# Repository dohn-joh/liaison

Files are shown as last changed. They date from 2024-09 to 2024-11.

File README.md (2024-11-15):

cover_photo

# Liaison
`Liaison` is a wireless 36-key split keyboard that leverages custom keycaps, splay, and tenting for ergonomics.

**Video showcase**:  
[Fit and layout](https://vimeo.com/1022366207)  
[Typing test](https://vimeo.com/1022366241)

***

# Components

## Case and Tenting Legs
[Here](case) you can find models for the case and magsafe tenting legs.  
Print 1 of each of the following:
* [top left](case/case_top_left.step)
* [top right](case/case_top_right.step)
* [bottom left](case/case_bottom_left.step)
* [bottom right](case/case_bottom_right.step)

[Tenting legs](case/magsafe_tenting_leg) (optional)  
[Dongle case](https://github.com/dohn-joh/dongle-zmk) (optional)

## Required Parts
|Part|Quantity|Link|
|-|:-:|-|
|Microcontroller: Xiao nRF52840|1|https://www.seeedstudio.com/Seeed-XIAO-BLE-nRF52840-p-5201.html|
|Battery: 301230 with molex pico ezmate connector|1|Select L0040. https://www.aliexpress.us/item/3256802674181210.html|
|Battery connector: molex pico ezmate 1x02|1|Select 2P. https://www.aliexpress.us/item/3256805726980487.html|
|Power button: 1208YD|1|https://www.aliexpress.us/item/3256801267126259.html|
|Reset button: SKHLLCA010|1|https://www.aliexpress.us/item/3256805176534062.html|
|M2 heatset inserts (OD:3.2, Height: 2-3mm)|8|https://www.aliexpress.us/item/3256804856964661.html|
|Switches|36|Your choice of choc v1 or v2. Recommended: Lofree ghost, swap springs|
|Kailh Choc PG1350 Hot Swap Sockets|36|https://www.aliexpress.us/item/3256803687338432.html|
|Silicone sheet for feet|1|https://www.amazon.com/dp/B09NW63JLC|
|Keycaps|36|Your choice. Recommended: [low profile DES](https://github.com/dohn-joh/PseudoMakeMeKeyCapProfiles) + [lever keycaps](https://github.com/dohn-joh/keycaps)|

> [!NOTE]
> Keycap dimensions must be ≤17.85mm wide and ≤18mm deep. All standard choc keycaps will fit.

## Optional Parts for Tenting Legs and Magnetic USB
|Part|Quantity|Link|
|-|:-:|-|
|Magsafe puck: Vrig MG-01|2|https://www.aliexpress.us/item/3256804940825578.html|
|Magsafe plate|2|https://www.amazon.com/dp/B09B6XGTWL|
|1/4" thread screw ~9mm|2|There are cheaper sources out there, but here is a link: https://www.amazon.com/dp/B01MS60KSY|
|Magnetic USB connector/cable: Netdot Gen10|2|https://www.amazon.com/dp/B07MBD3FZD|

## Firmware
[Here](https://github.com/dohn-joh/liaison-zmk-module) you can find the liaison's ZMK module. The firmware is configured for dongle usage, however you may fork the repo if you prefer to not use a dongle.

# Build Guide

**1. Order the pcb and acquire the case**
* Download the [left](ergogen/output/pcbs/production/Left_v1.0.0.zip) and [right](ergogen/output/pcbs/production/Right_v1.0.0.zip) pcb zip files.
* Upload the zip files to your pcb manufacturer of choice, then place an order. I used jlcpcb.
* Acquire the case:
    * If you own a 3d printer: print the [case](README.md#case-and-tenting).
    * If you don't own a 3d printer: order the case prints using [these files](README.md#case-and-tenting).

**2. Order [parts](README.md#required-parts)**

**3. Flash and test the microcontrollers**
> [!IMPORTANT]
> **Flash your microcontrollers with firmware and test them before doing any soldering.** Once the microcontrollers are soldered, they will be nearly impossible to remove without the right tools.
* Flash the [firmware](https://github.com/dohn-joh/liaison-zmk-module).
* Test to make sure that the microcontrollers are working and not defective (defective units are rare, but it happens).

**4. Solder components to top face of pcb**
* Set your soldering iron to 350C.
* Solder the microcontrollers, diodes, [reset switch](https://github.com/GEIGEIGEIST/TOTEM/blob/main/docs/buildguide.md#reset-switches), power switch, and battery connector to the top face of the pcb.
* The battery connector can be tricky to solder. But once you get the hang of it, it's pretty easy. Here are some tips from Kim:
    > Apply flux on both the pcb pads and battery connector pins  
    Tin both corner pads with solder  
    Solder connector to the first corner by applying heat to the corner metal pin from above  
    Then do the same for the second corner  
    Apply more flux to connector pins and PCB pads  
    Apply solder to underside of soldering tip  
    Drag iron from side to side over the contacts until they are soldered. The solder will just jump to where it needs to go  
    Make sure to clean the flux thoroughly
* The power button needs to face downward. Trim the power switch legs to size before installing. Secure the power switch in place with kapton tape after soldering.

**5. Check your work**
* This step is optional, but I like to check my work before moving on to soldering the other side of the pcb.
* Make sure all diodes are oriented correctly. All lines or arrows should be pointing left.
* Set your multimeter to continuity mode.
* Check connections and look for bridging.
* Fix any solder joints as needed.

**6. Solder components to bottom face of pcb**
> [!IMPORTANT]
> Hotswap socket orientation matters. The sockets must align with the silkscreen or the bottom case will not fit.
* Solder the hotswap sockets to the bottom face of the pcb.
* Optional: check your work with a multimeter.

**7. Battery installation**
* Plug the battery into the connector.
* Use kapton tape to secure the battery within the silkscreen outline.

**8. Case assembly**
* With your soldering iron set to 300C, push heatset inserts into the 4 holes on the top case.
* Insert the pcb.
* Attach the bottom case and secure it in place with the M2 screws.
    * If the bottom case doesn't sit flush in the area around the reset switch, then you may need to trim the reset switch legs.
* Cut silicone sheet to size and adhere to the corners of the bottom case.
* Insert the switches and keycaps.

**9. (Optional) Tenting assembly**
* Screw the magsafe pucks onto the tenting legs.
* Adhere magsafe plate to bottom case.
* Cut silicone sheet to size and adhere to bottom of tenting legs.

***

# Photos





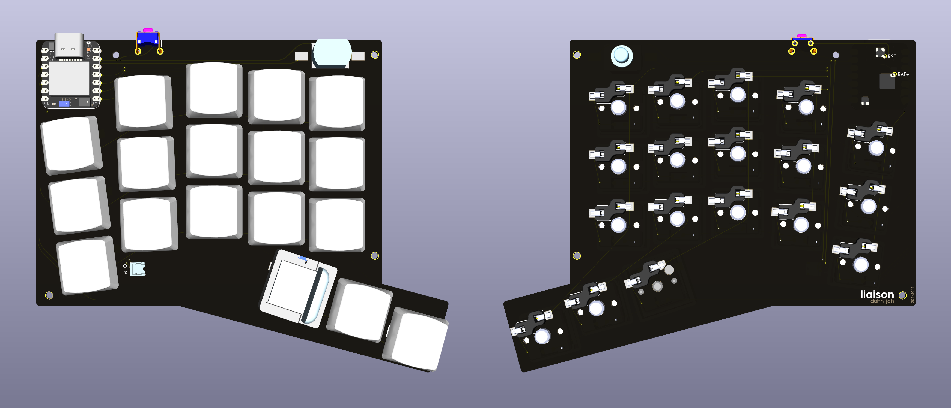
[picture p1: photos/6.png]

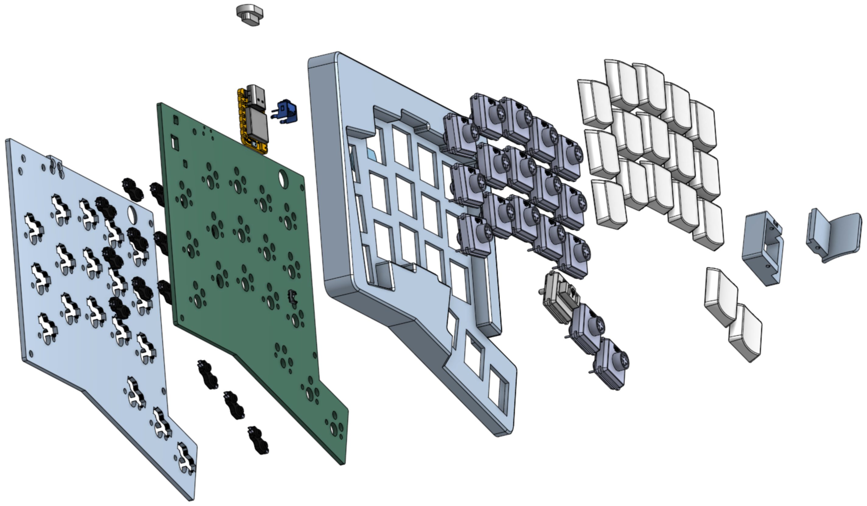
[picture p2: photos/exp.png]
exp


***

## Thanks
These people and many more helped make this keyboard possible. Yall are legends.
```
MrZealot
Pseudoku
petejohanson
caksoylar(bravekarma)
jcmkk3
ceoloide
infused-kim
Flatfootfox
sadekbaroudi
zzeneg
joelspadin
wolfwood
claussen
Geist
rmwphd(atinyzubat)
fish
Araxia
honorless
elkepenin
reeves
```

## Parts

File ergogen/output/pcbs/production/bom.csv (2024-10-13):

Designator | Footprint | Quantity | Value | LCSC Part #
CONN1 | conn_molex_pico_ezmate_1x02 | 1
D1, D10, D11, D12, D13, D14, D15, D16, D17, D18, D2, D3, D4, D5, D6, D7, D8, D9 | ComboDiode | 18
H1, H2, H3 | mounting_hole | 3
MCU1 | xiao_smd_xl_cutout_minimal | 1
S19 | SKHLLCA010 | 1 | SKHLLCA010
SW1 | 1208YD | 1

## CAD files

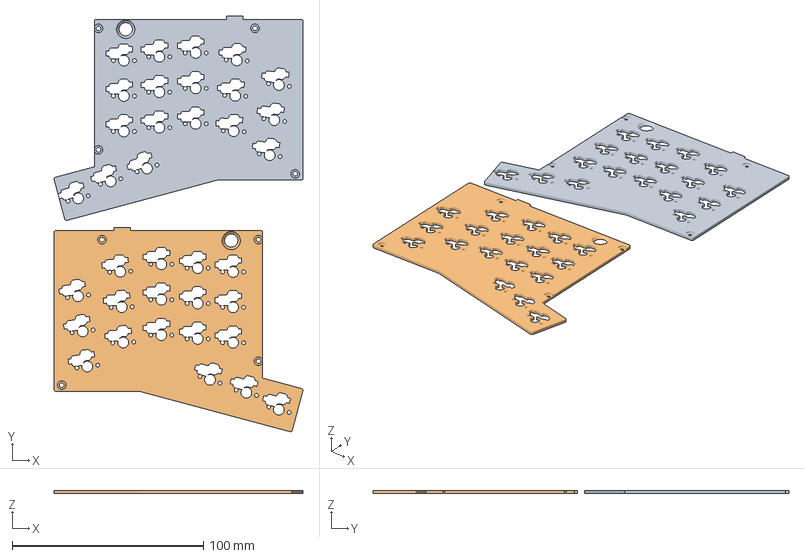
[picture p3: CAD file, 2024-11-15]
case/case_bottom_orcaslicer_settings.3mf
130.1 x 217.1 x 1.70 mm
test.step
test2.step

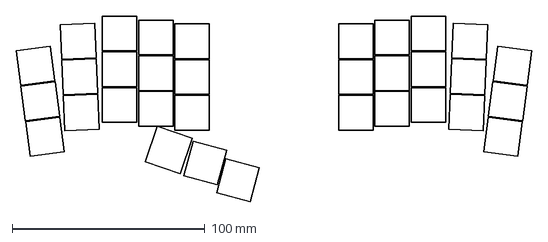
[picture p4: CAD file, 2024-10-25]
ergogen/output/outlines/keycaps.dxf
267.0 x 96.2 mm

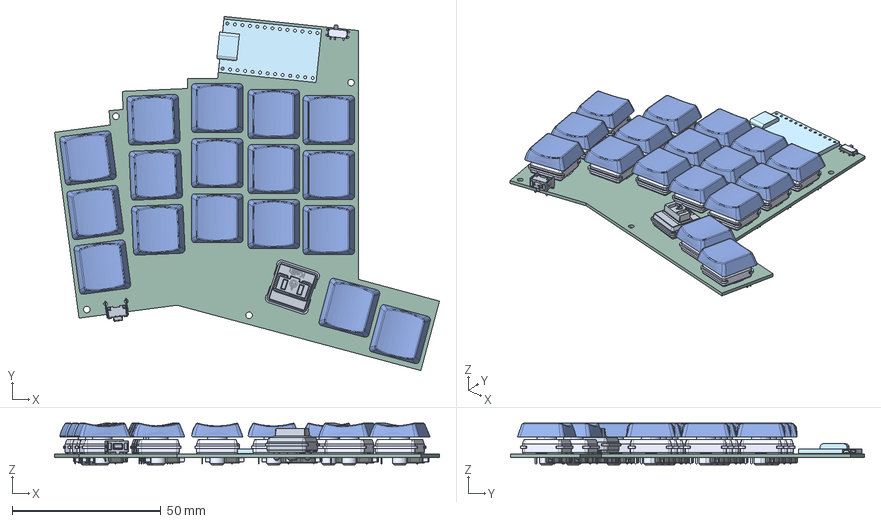
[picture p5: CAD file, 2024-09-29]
ergogen/output/pcbs/l.step
129.4 x 119.0 x 14.0 mm
SKHLLC
supermini-nrf52840
PCM12SMTR
Kailh_PG1352 x 17
PG1350 x 18
cap x 17
Kailh LP Choc Burnt Orange
Sybil_PCB

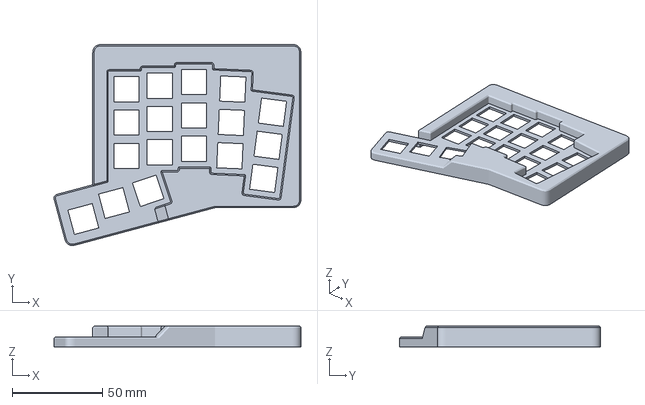
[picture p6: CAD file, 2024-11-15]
case/case_top_orcaslicer_settings.3mf
137.0 x 111.5 x 11.5 mm

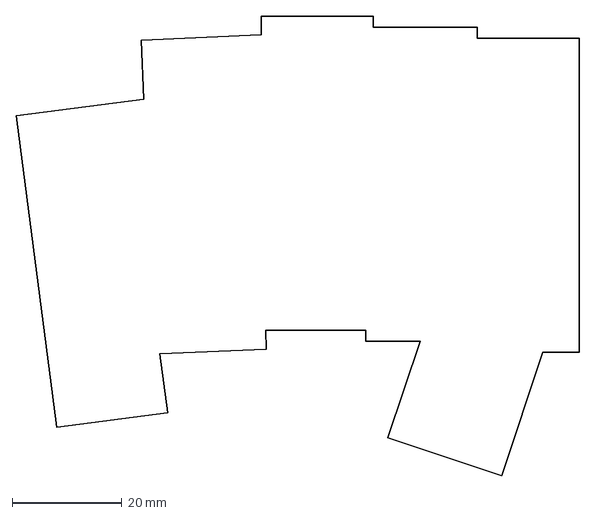
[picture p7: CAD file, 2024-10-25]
ergogen/output/outlines/key_walls.dxf
102.5 x 83.7 mm

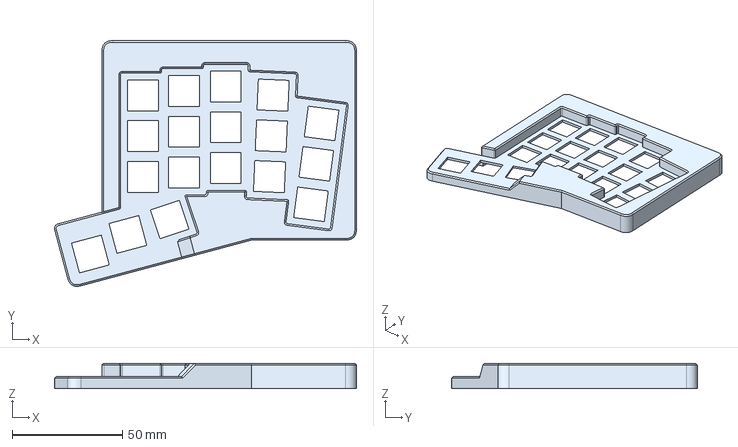
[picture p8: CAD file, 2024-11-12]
case/case_top_right.step
137.0 x 111.5 x 11.5 mm

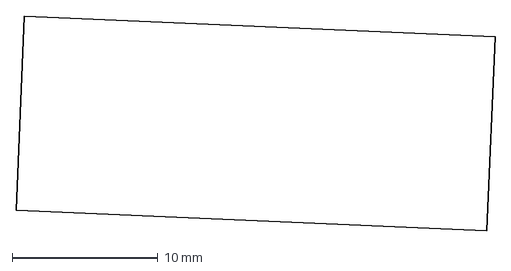
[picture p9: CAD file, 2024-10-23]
ergogen/output/outlines/battery_cutout_right.dxf
32.8 x 14.7 mm

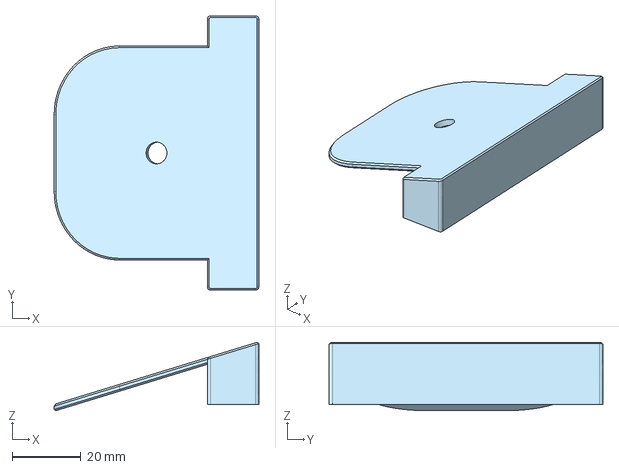
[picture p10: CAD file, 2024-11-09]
case/magsafe_tenting_leg.step
59.8 x 80.0 x 20.0 mm

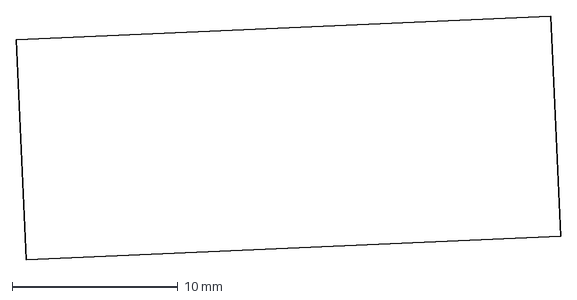
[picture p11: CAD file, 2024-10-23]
ergogen/output/outlines/battery_cutout_left.dxf
32.8 x 14.7 mm

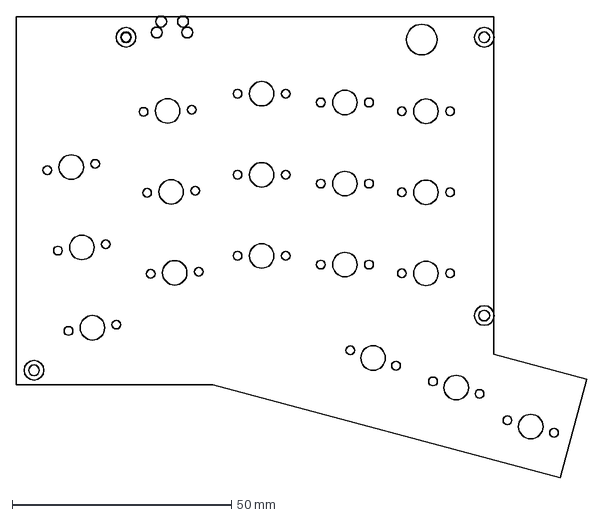
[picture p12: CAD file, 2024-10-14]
ergogen/output/outlines/case_bottom_left.dxf
130.3 x 105.4 mm

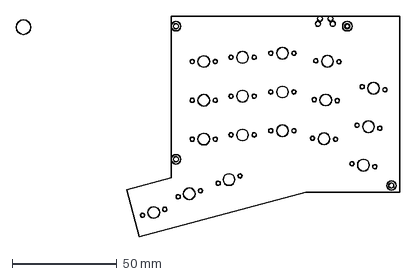
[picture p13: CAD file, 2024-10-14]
ergogen/output/outlines/case_bottom_right.dxf
183.1 x 105.4 mm

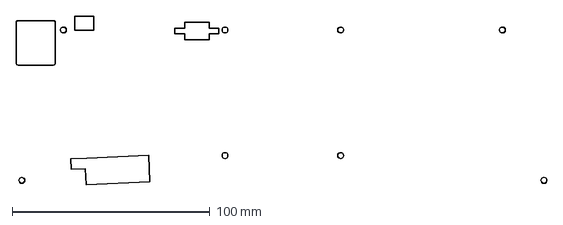
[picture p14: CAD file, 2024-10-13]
ergogen/output/outlines/case_top_cutouts.dxf
268.4 x 85.0 mm

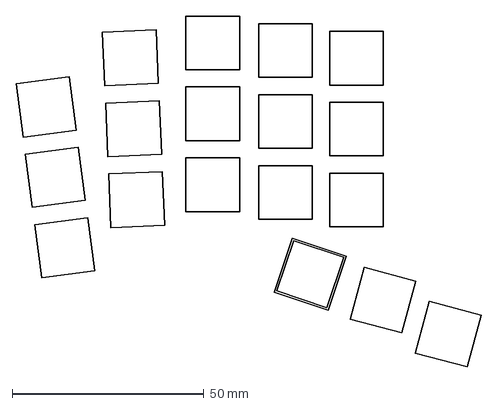
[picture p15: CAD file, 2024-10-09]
ergogen/output/outlines/switch_cutouts.dxf
121.3 x 91.5 mm

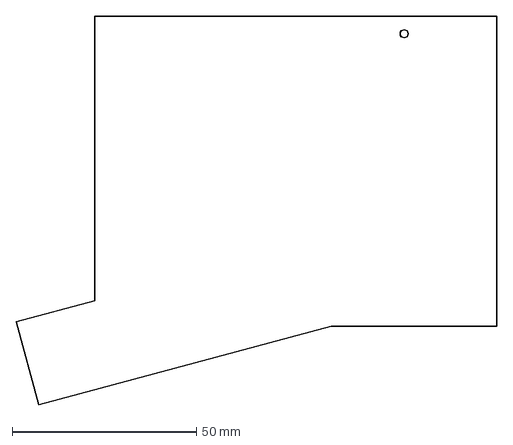
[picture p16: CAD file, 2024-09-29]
ergogen/output/outlines/pcb_right.dxf
130.3 x 105.3 mm

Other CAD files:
case/case_top_left.step
ergogen/output/outlines/pcb_left.dxf
ergogen/output/outlines/screws.dxf

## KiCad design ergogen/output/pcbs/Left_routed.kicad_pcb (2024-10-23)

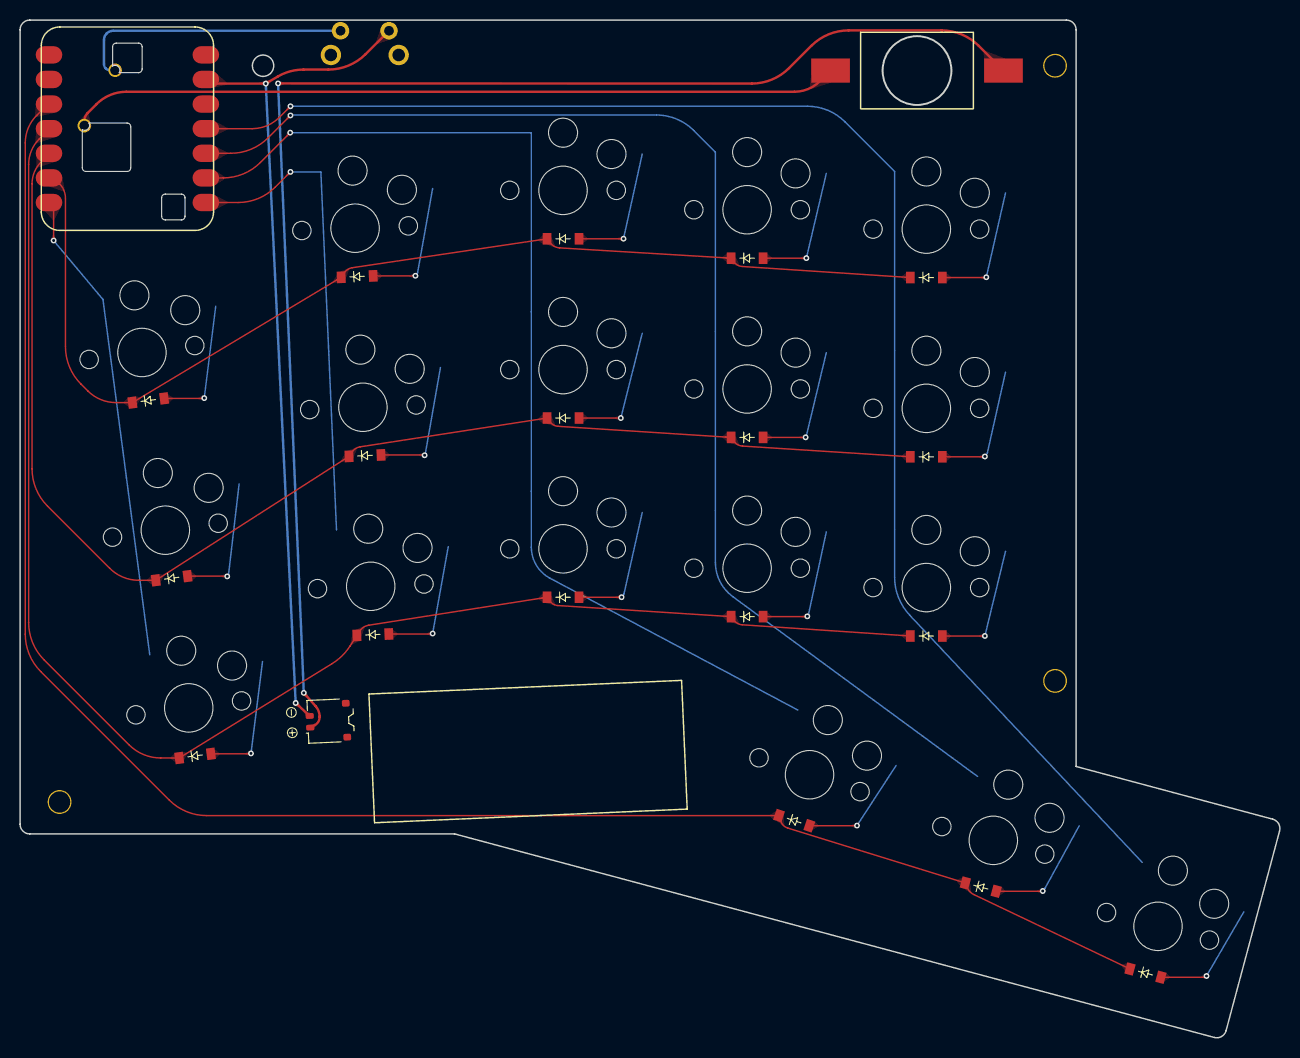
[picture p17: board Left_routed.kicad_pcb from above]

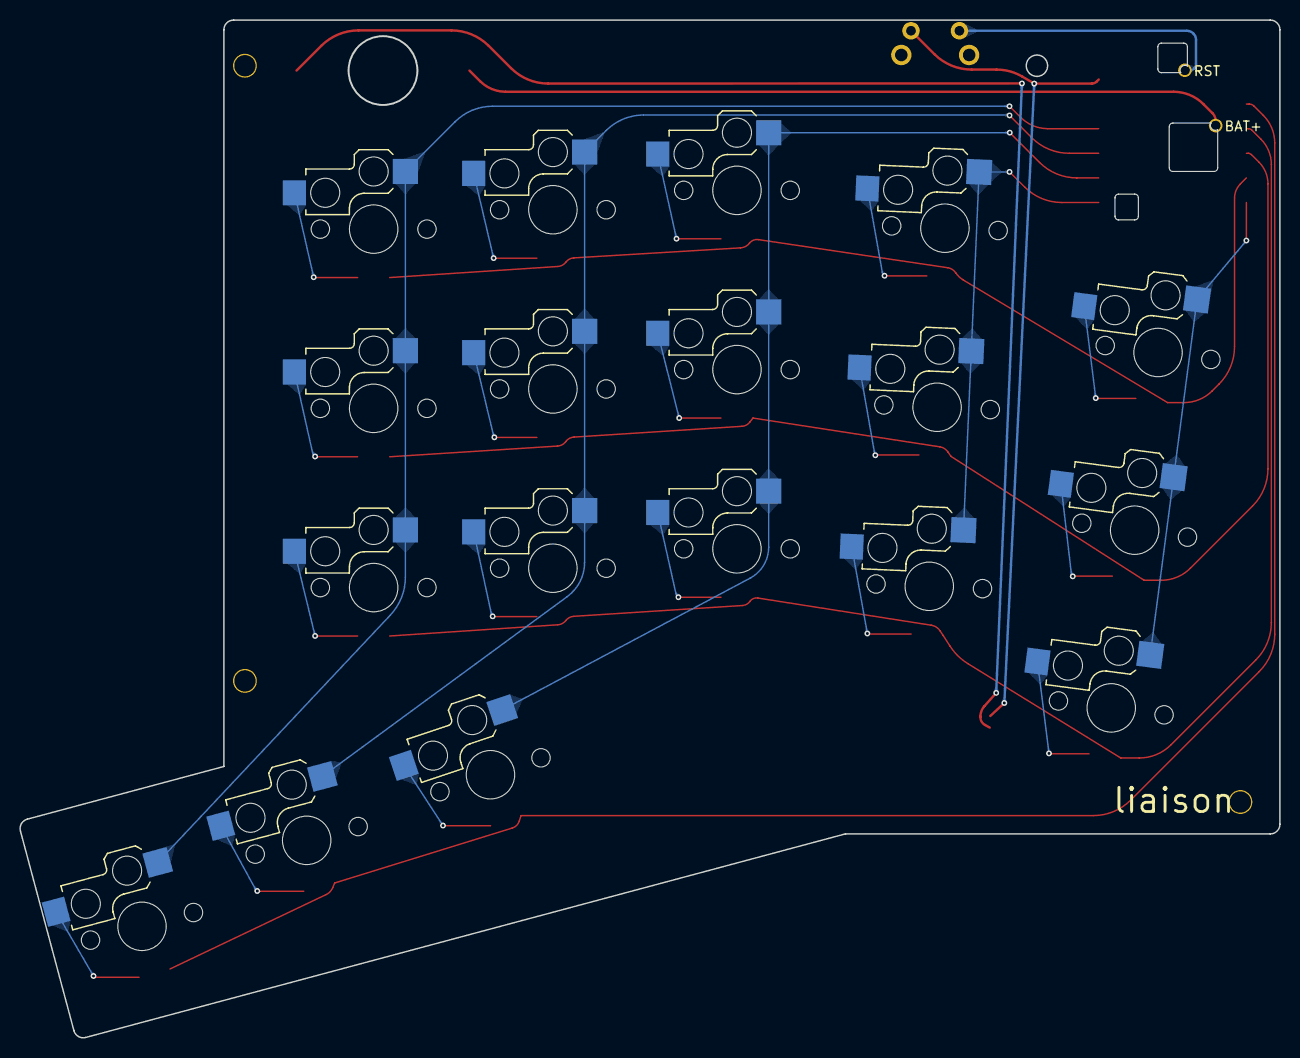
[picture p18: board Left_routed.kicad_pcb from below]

Board: 2 copper layers, 130.0 x 105.0 mm, 44 parts (18 on the bottom side), 31 nets.

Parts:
CONN1: conn_molex_pico_ezmate_1x02
D1, D2, D3, D4, D5, D6, D7, D8, D9, D10, D11, D12, D13, D14, D15, D16, D17, D18: ComboDiode
H1, H2, H3: mounting_hole
ICON1: icon_bat
MCU1: xiao_smd_xl_cutout_minimal
S1, S2, S3, S4, S5, S6, S7, S8, S9, S10, S11, S12, S13, S14, S15, S16, S17, S18: switch_choc_v1_v2
S19: SKHLLCA010
SW1: 1208YD

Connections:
BAT: MCU1.19, SW1.1
BAT_CONN: CONN1.1, SW1.2
C0: MCU1.7, S1.1, S2.1, S3.1
C1: MCU1.8, S4.1, S5.1, S6.1
C2: MCU1.9, S7.1, S8.1, S9.1, S16.1
C3: MCU1.10, S10.1, S11.1, S12.1, S17.1
C4: MCU1.11, S13.1, S14.1, S15.1, S18.1
GND: CONN1.2, MCU1.13, S19.2
R0: D3.1, D6.1, D9.1, D12.1, D15.1, MCU1.6
R1: D2.1, D5.1, D8.1, D11.1, D14.1, MCU1.5
R2: D1.1, D4.1, D7.1, D10.1, D13.1, MCU1.4
R3: D16.1, D17.1, D18.1, MCU1.3
RST: MCU1.17, S19.1
base_cluster: D17.2, S17.2
extension_cluster: D18.2, S18.2
flexion_cluster: D16.2, S16.2
index_bottom: D10.2, S10.2
index_home: D11.2, S11.2
index_top: D12.2, S12.2
inner_bottom: D13.2, S13.2
inner_home: D14.2, S14.2
inner_top: D15.2, S15.2
middle_bottom: D7.2, S7.2
middle_home: D8.2, S8.2
middle_top: D9.2, S9.2
pinky_bottom: D1.2, S1.2
pinky_home: D2.2, S2.2
pinky_top: D3.2, S3.2
ring_bottom: D4.2, S4.2
ring_home: D5.2, S5.2
ring_top: D6.2, S6.2

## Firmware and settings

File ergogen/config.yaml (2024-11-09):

units:
  capx: 17.85
  capy: 18
  capthumbx: 17.95
  capthumby: 18.35
  capleverx: 19.12
  caplevery: 19.32
  kx: 19
  ky: 18.5
  inner_spread: kx-0.5
  pinky_splay: 5
  ring_splay: 2.5
  thumb_offsetx: 0.25kx
  switch_xy_mx: 14 # switch hole
  switch_xy_choc: 13.8
  angle: 22 # was 27.5
  # sf: 19.151 # may want to change this for fab
  sf: 19.151
  
  # pcb rectangle dimensions
  pcbx: 109
  pcby: 84

  # mirror distance
  md: 250

  ## nice!nano dimensions (from Nicell himself)
  # mcux: 18
  # mcuy: 33.4
  ## supermini dimensions
  # mcux: 18.1 # with 0.1mm tolerance for fr4 variance
  # mcuy: 33.85 # length from usb to end of pcb
  ## promicro footprint dimensions
  # mcux: 17.78
  # mcuy: 33.02 # board only, no usb
  # xiao nrf52840 dimensions
  mcux: 17.78
  mcuy: 21
  # netdot usb adapter dimensions
  ndx: 12 # actual is ~10.82 at widest section
  ndy: 6 # actual is 5.4 while plugged in
  # space between keycap and case wall
  wallx: 1.25
  wally: 1.1

  # joycon battery dimensions plus tolerance
  # bcx: 24.5+0.7
  # bcy: 52+0.7

  # 301230 battery dimensions
  bcx: 31.5+0.8
  bcy: 12.5+0.8

  # screw hole diameter (M2)
  scd: 2.2
  # screw head diameter ~3.3
  # heatset hole diameter for 3.2 OD inserts
  heatset: 3
  # screw hole diameter for case bottom
  scb: 2.45
  # screwhead diameter
  sch: 4.5

points:
  zones:
    matrix:
      anchor:
        # Fix placement on KiCAD sheet.
        shift: [100, -100]
        rotate: pinky_splay + ring_splay
      key:
        width: capx
        height: capy
        padding: ky
        spread: kx
        autobind: 0
      columns:
        pinky:
          rows:
            top:
              bind: [0, 0.5kx, 0.5ky, 0]
            home:
              bind: [0, 0.5kx, 0, 0]
            bottom:
              bind: [0, 0, 0, 0]
          key:
            column_net: C0
            tags: hotswap
        ring:
          rows:
            top:
              bind: [0, 0.5kx, 0.5ky, 0]
            home:
              bind: [0.5ky, 0.5kx, 0, 0]
            bottom:
              bind: [0.5ky, 0, 0, 0.5kx]
          key:
            column_net: C1
            stagger: 10 # was 10
            spread: kx+1
            splay: -pinky_splay
            origin: [0, -3]
            tags: hotswap
        middle:
          rows:
            home:
              bind: [0.5ky, 0.5kx, 0, 0]
            bottom:
              bind: [0.5ky, 0.5kx, 0.5ky, 0.5kx]
          key:
            column_net: C2
            stagger: 3 # was 2
            spread: kx+1
            splay: -ring_splay
            tags: hotswap
        index:
          rows:
            top:
              bind: [0, 0, 0, 0]
            home:
              bind: [0.5ky, 0.5kx, 0, 0]
            bottom:
              bind: [0.5ky, 0.5kx, 0, 0]
          key:
            column_net: C3
            stagger: -2
            tags: hotswap
        inner:
          rows:
            top:
              bind: [0, 0, 0, 0.5kx]
            home:
              bind: [0.5ky, 0, 0, 0]
            bottom:
              bind: [0.5ky, 0, 0.5ky, 0]
              tags: hotswap
          key:
            column_net: C4
            spread: inner_spread
            stagger: -2
      rows:
        bottom:
          row_net: R2
        home:
          row_net: R1
        top:
          row_net: R0
    thumb:
      anchor:
        ref: matrix_index_bottom
        shift: [thumb_offsetx-4.82+3, -30.1+3]
      key:
        width: capx
        height: capy
        padding: ky
        spread: kx+0.7
        autobind: 0
      columns:
        flexion:
          rows:
            cluster:
              bind: [0.5ky, 0, 0, 0]
          key:
            splay: -20
            orient: 47.5
            shift: [152.1536-148.8676+2.5, -(139.4486-142.9557)] # x was +1.6
            rotate: -46
            column_net: C2
        base:
          rows:
            cluster:
              bind: [0, 18.715231, 0, 0]
          key:
            splay: 5
            stagger: 2.5+4
            spread: cx+2.5
            column_net: C3
            adjust:
              orient: angle - pinky_splay - ring_splay + 20 + 3
              shift: [0.887, -0.4617]
              rotate: -angle + pinky_splay + ring_splay - 20 - 3
        extension:
          rows:
            cluster:
              bind: [0, 0, 0, 90]
          key:
            column_net: C4
            stagger: -4
      rows:
        cluster:
          row_net: R3
    ref_polygon:
      anchor:
    ref_mcu:
      anchor:
        ref: matrix_pinky_top
        shift: [-1.5, 23.1]
        orient: -7.5
    ref_reset:
      anchor:
        ref: ref_mcu
        shift: [24.5, 8.858]
    ref_power:
      anchor:
        ref: ref_mcu
        shift: [81.5, 6.]
    ref_battery_connector:
      anchor:
        ref: matrix_ring_bottom
        shift: [-5, -14+0.303]
        rotate: 90
    ref_battery_icon:
      anchor:
        ref: ref_battery_connector
        shift: [0, 3.75]
    ref_jlc_text:
      anchor:
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

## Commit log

2024-09-30 update sw cut
    [switch_cutouts.dxf]
2024-10-09 fix xiao footprint
    [Left.kicad_pcb, Right.kicad_pcb, switch_cutouts.dxf]
2024-10-13 update config
    [Left.kicad_pcb, Left_render.kicad_pcb, Left_routed.kicad_pcb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]
2024-10-23 add battery outlines to pcb
    [Left_render.kicad_pcb, Left_routed.kicad_pcb, Right_routed.kicad_pcb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]
2024-10-25 update key_walls
    [key_walls.dxf, keycaps.dxf]
2024-11-09 update case files
    [case_top_left.step, left_top.step, magsafe_tenting_leg.step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]
2024-11-15 add slicer settings
    [case_bottom_orcaslicer_settings.3mf, case_top_orcaslicer_settings.3mf]
